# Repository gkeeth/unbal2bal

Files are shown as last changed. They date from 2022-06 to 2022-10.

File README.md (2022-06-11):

# Unbalanced to Balanced Audio Converter

Intended for measurements of unbalanced sources with a balanced soundcard.

Powered from +/-12V DC on a 3-pin Mini DIN connector.
Outputs (unbuffered) +/-12V DC on a 4-pin Mini DIN connector, to allow daisy chaining.

## License
This work is licensed under a [Creative Commons Attribution-ShareAlike 4.0
International License][cc-by-sa].

[][cc-by-sa]

[cc-by-sa]: http://creativecommons.org/licenses/by-sa/4.0/
[cc-by-sa-image]: https://licensebuttons.net/l/by-sa/4.0/88x31.png
[cc-by-sa-shield]: https://img.shields.io/badge/License-CC%20BY--SA%204.0-lightgrey.svg

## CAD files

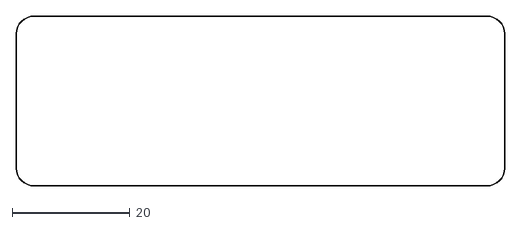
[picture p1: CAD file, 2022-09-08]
mechanical/panel_outline-BodySketch.dxf
82.8 x 28.8

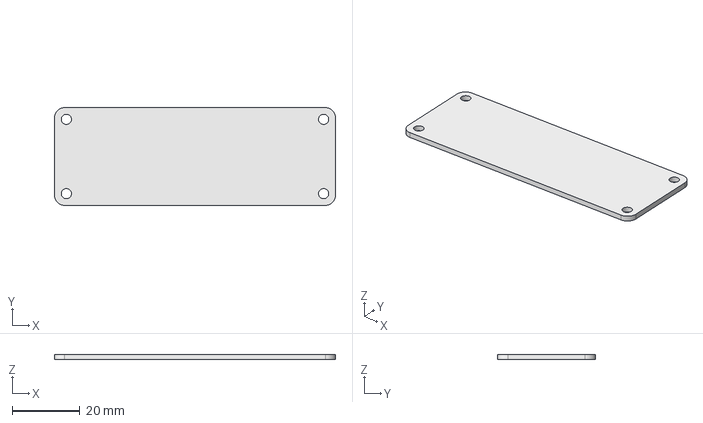
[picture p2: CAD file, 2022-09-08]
mechanical/panel_outline.FCStd
82.8 x 28.8 x 1.60 mm

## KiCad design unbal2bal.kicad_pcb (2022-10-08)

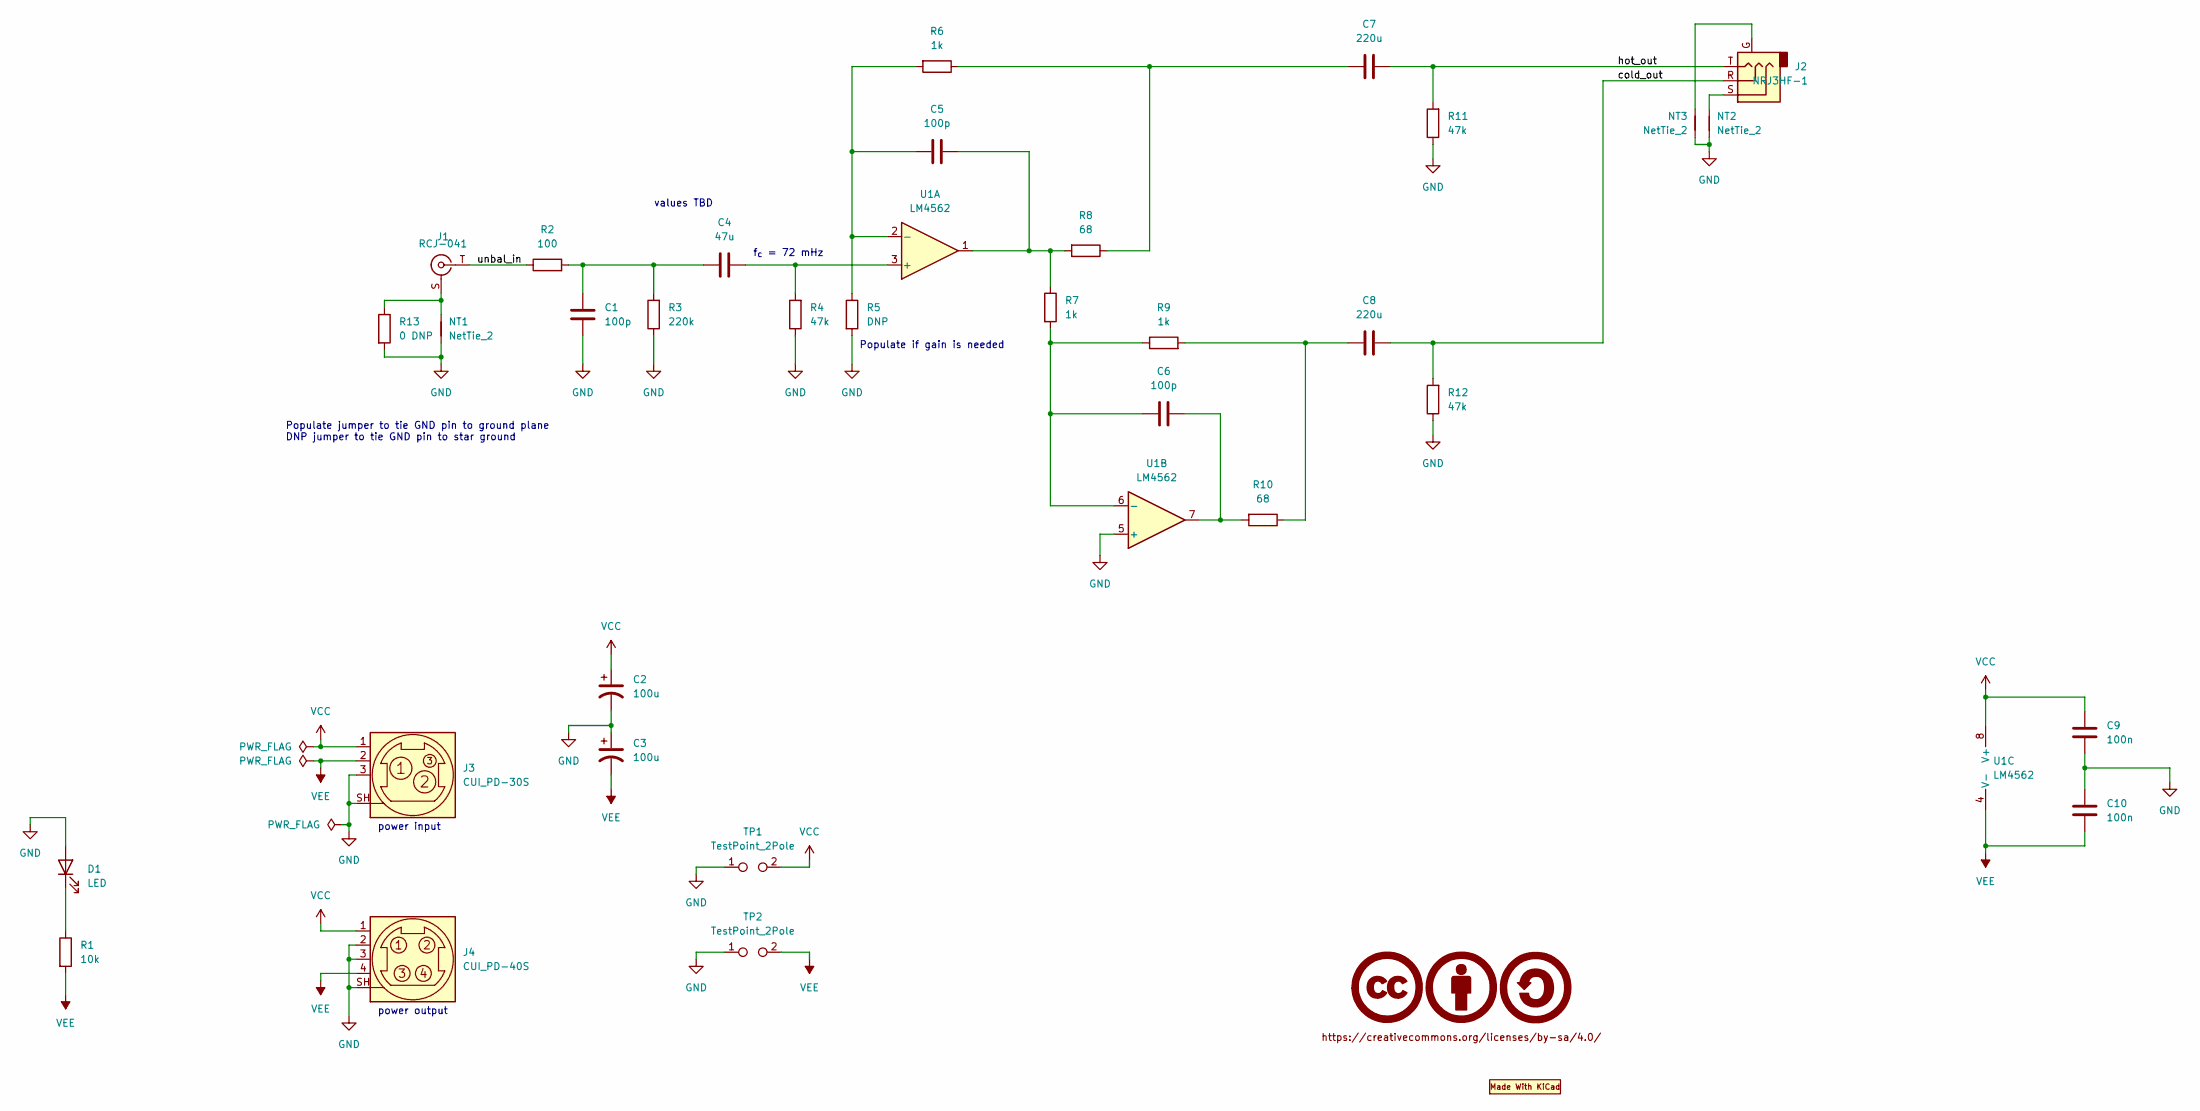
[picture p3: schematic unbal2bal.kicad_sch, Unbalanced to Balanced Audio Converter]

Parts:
C1, C5, C6: 100p; C_0805_2012Metric
C2, C3: 100u; CP_Radial_D6.3mm_P2.50mm; Voltage Rating 35V; Manufacturer PN UVR1V101MED
C4: 47u; C_Radial_D10.0mm_H16.0mm_P5.00mm; Voltage Rating 35V; Manufacturer PN UES1V470MPM
C7, C8: 220u; C_Radial_D12.5mm_H20.0mm_P5.00mm_Horizontal; Voltage Rating 35V; Manufacturer PN UVP1V221MHD
C9, C10: 100n; C_0805_2012Metric
D1: LED; LED_D5.0mm_Horizontal_O3.81mm_Z3.0mm
J1: RCJ-041; RCA_CUI_RCJ-04x_Horizontal; Manufacturer PN RCJ-041
J2: NRJ3HF-1; Jack_6.35mm_Neutrik_NRJ3HF-1_Horizontal; Manufacturer PN NRJ3HF-1
J3: CUI_PD-30S; Power-DIN_CUI_PD-30S_Horizontal; Manufacturer PN PD-30S
J4: CUI_PD-40S; Power-DIN_CUI_PD-40S_Horizontal; Manufacturer PN PD-40S
LOGO1: Logo_MadeWithKiCad; KiCad-Logo2_5mm_SilkScreen
LOGO2: CC-BY-SA_0.5in; CC-BY-SA_SilkScreenTop_Small
NT1, NT2: NetTie_2; NetTie-2_SMD_Pad1.0mm
NT3: NetTie_2; NetTie-2_SMD_Pad0.5mm
R1: 10k; R_1206_3216Metric
R2: 100; R_1206_3216Metric
R3: 220k; R_1206_3216Metric
R4, R11, R12: 47k; R_1206_3216Metric
R5: DNP; R_1206_3216Metric
R6, R7, R9: 1k; R_1206_3216Metric
R8, R10: 68; R_1206_3216Metric
R13: 0 DNP; R_1206_3216Metric
TP1, TP2: TestPoint_2Pole; PinHeader_1x02_P2.54mm_Vertical
U1: LM4562; SOIC-8_3.9x4.9mm_P1.27mm

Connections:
/cold_out: C8.2, J2.R, R12.2
/hot_out: C7.2, J2.T, R11.2
/unbal_in: J1.T, R2.1
GND: C1.2, C2.2, C3.1, C9.2, C10.1, D1.2 (A), J3.3, J3.SH (Shield), J4.2, J4.3, J4.SH (Shield), NT1.1, NT2.2, NT3.2, R3.1, R4.1, R5.2, R11.1, R12.1, R13.2, TP1.1, TP2.1, U1.5 (+)
unnamed: C1.1, C4.1, R2.2, R3.2
unnamed: C4.2, R4.2, U1.3 (+)
unnamed: C5.1, R5.1, R6.2, U1.2 (-)
unnamed: C5.2, R7.1, R8.2, U1.1
unnamed: C6.1, R7.2, R9.1, U1.6 (-)
unnamed: C6.2, R10.2, U1.7
unnamed: C7.1, R6.1, R8.1
unnamed: C8.1, R9.2, R10.1
unnamed: D1.1 (K), R1.1
unnamed: J1.S, NT1.2, R13.1
unnamed: J2.G, NT3.1
unnamed: J2.S, NT2.1
VCC: C2.1, C9.1, J3.1, J4.1, TP1.2, U1.8 (V+)
VEE: C3.2, C10.2, J3.2, J4.4 (Shield), R1.2, TP2.2, U1.4 (V-)

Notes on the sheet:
power output
values TBD
f_{c} = 72 mHz
Populate jumper to tie GND pin to ground plane DNP jumper to tie GND pin to star ground
power input
Populate if gain is needed

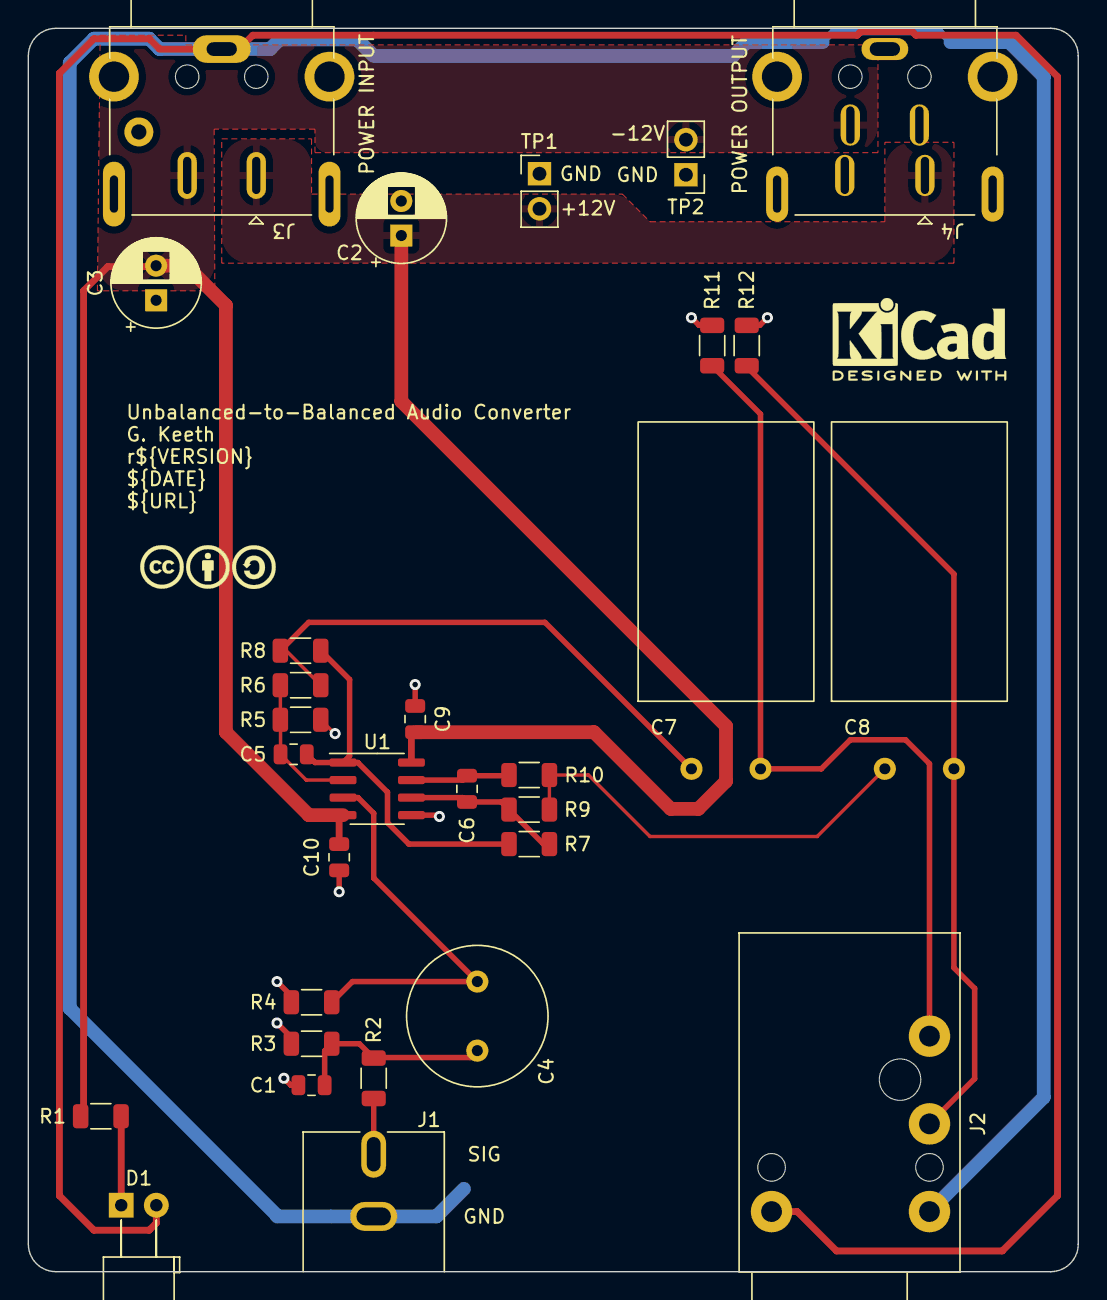
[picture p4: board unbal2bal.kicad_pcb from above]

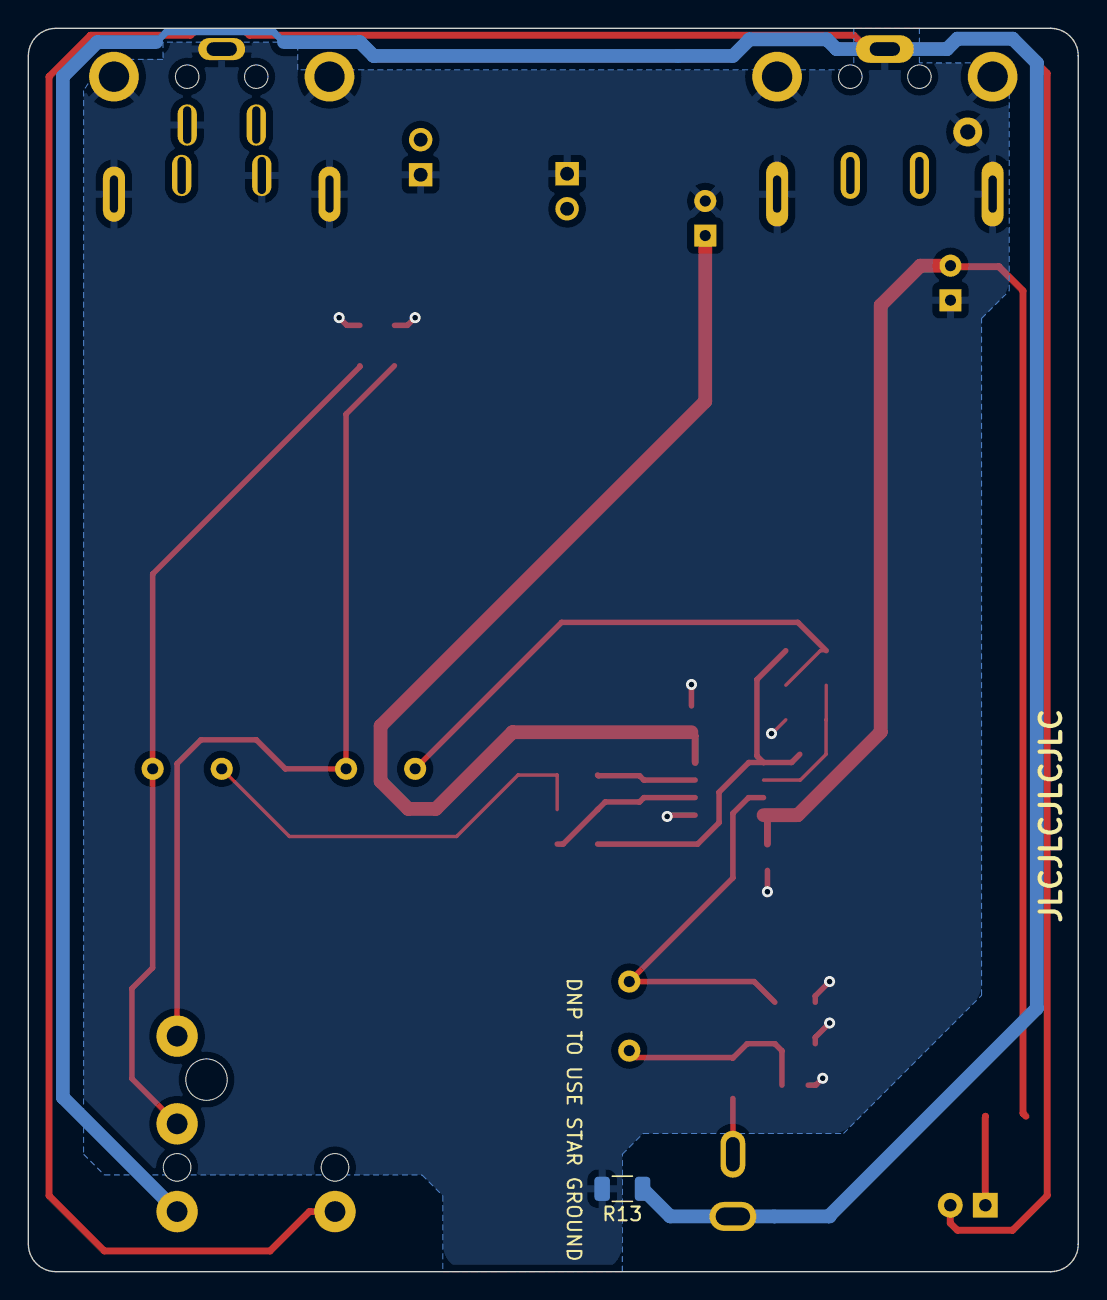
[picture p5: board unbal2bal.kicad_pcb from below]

Board: 2 copper layers, 76.0 x 90.0 mm, 36 parts (3 on the bottom side), 18 nets.

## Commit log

2022-06-11 mostly complete layout
    [unbal2bal.kicad_pcb, unbal2bal.kicad_sch]
2022-06-11 update TODO
    [unbal2bal.kicad_pcb]
2022-06-11 remove renamed project files
    [se2bal.kicad_pcb, se2bal.kicad_sch]
2022-06-12 switch RCA jack to a nicer model
    [unbal2bal.kicad_pcb, unbal2bal.kicad_sch]
2022-06-12 update TODOs
    [unbal2bal.kicad_pcb]
2022-06-12 move output coupling caps to horizontal to fit into enclosure
    [unbal2bal.kicad_pcb, unbal2bal.kicad_sch]
2022-06-16 add SVG source files for mini-din label footprints
2022-06-16 add back panel pcb
    [back_panel.kicad_pcb, back_panel.kicad_sch]
2022-06-16 minor updates, labels, etc
    [unbal2bal.kicad_pcb, unbal2bal.kicad_sch]
2022-06-16 mechanical holes in front panel. needs labels
    [front_panel.kicad_pcb, front_panel.kicad_sch]
2022-06-18 update grounding
    [unbal2bal.kicad_pcb, unbal2bal.kicad_sch]
2022-06-18 add front panel
    [front_panel.kicad_pcb]
2022-06-18 minor change from plotting gerbers
    [back_panel.kicad_pcb, front_panel.kicad_pcb, unbal2bal.kicad_pcb]
2022-06-18 update part numbers
    [unbal2bal.kicad_sch]
2022-07-05 fix vertical position of RCA jack cutout
    [front_panel.kicad_pcb]
2022-07-05 change to lower profile 1/4in jack
    [unbal2bal.kicad_pcb, unbal2bal.kicad_sch]
2022-07-06 update front panel cutout for 1/4in jack
    [front_panel.kicad_pcb]
2022-08-28 Adjust DIN connector locations
    - move miniDIN (power) connectors backwards 1.6mm to be flush with
    outside of case for connector clearance
    - not going to increase size of cutouts for miniDIN connectors in back
    panel. Moving the connectors fixes the connector clearance issue, and
    existing cutouts have a minimal amount of slop so hopefully that
    should be enough for assembly tolerances.
    - rework star grounding as a result of moving power connectors
    - increase annular ring size on miniDIN connector footprints
    [unbal2bal.kicad_pcb]
2022-08-28 add mask cutout for balanced jack panel grounding
    [front_panel.kicad_pcb, unbal2bal.kicad_pcb]
2022-08-28 add 3D model for output jack, update date
    [unbal2bal.kicad_pcb]
2022-08-28 update front panel date on silk
    [front_panel.kicad_pcb]
2022-09-06 increase annular ring size on rca connector, bump to r2
    [unbal2bal.kicad_pcb]
2022-09-08 add logo to front panel (r3)
    [front_panel.kicad_pcb]
2022-09-08 add mechanical files
    [panel_outline-BodySketch.dxf, panel_outline.FCStd]
2022-10-08 add power DIN source svgs
2022-10-08 swap to power DIN connectors for back panel
    [back_panel.kicad_pcb]
2022-10-08 switch to power DIN connectors on main board
    [unbal2bal.kicad_pcb, unbal2bal.kicad_sch]
2022-10-08 adjust text position on power-din labels
2022-10-08 swap to round cutouts for power-din connectors
    [back_panel.kicad_pcb]

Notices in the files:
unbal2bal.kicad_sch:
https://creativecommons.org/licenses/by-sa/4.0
